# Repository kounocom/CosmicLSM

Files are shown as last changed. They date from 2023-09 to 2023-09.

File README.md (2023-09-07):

# CosmicLSM - An ESP32-C3 based custom SlimeVR PCB
Board Image
## Notes:

 - Currently untested!
 - Designed for handsoldering, BOM contains parts that are "extended" on JLC, or straight up not present
 - CPL file not tested at all
 - See "Outputs/" for production files
 - IMUs that are compatible :
 - - BMI160
 - - BMI270
 - - BMI323(?)
 - - LSM6DSV
 - - LSM6DSV16X
 - - ICM-40608
 - - Potentially more, but there will be no firmware support, even for some of the ones listed above
 - Special thanks to Gorbit99 and wigwagwent for their help with making this <3

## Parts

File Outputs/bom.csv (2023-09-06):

Designator | Footprint | Quantity | Value | LCSC Part #
C1, C2, C5 | 603 | 3 | 10u | C1691
C10, C8, C9 | 603 | 3 | 100n | C1591
C11, C12 | 603 | 2 | 1u | C1592
C3 | 603 | 1 | 4u7 | C1705
C4 | 603 | 1 | 22u | IGNORE
C6, C7 | 603 | 3 | 22u | C59461
D1 | 603 | 1 | WHITE | C84265
D2 | 603 | 1 | RED | C264473
D3 | 603 | 1 | GREEN | C965804
J1 | JST_PH_S2B-PH-SM4-TB_1x02-1MP_P2.00mm_Horizontal | 1 | BAT | C295747
J2 | JST_GH_SM05B-GHS-TB_1x05-1MP_P1.25mm_Horizontal | 1 | JST GH | C189896
J3 | USB_C_Receptacle_XKB_U262-16XN-4BVC11 | 1 | USB_C_Receptacle_USB2.0 | C2765186
L1 | 603 | 1 | 2u2 | C285966
L2 | 805 | 1 | 1uH | C433051
R1, R12, R2, R3 | 603 | 4 | 1k | C21190
R10, R11, R15, R7, R8 | 603 | 5 | 150k | C22807
R13 | 603 | 1 | 112.5k | C25808
R14 | 603 | 1 | 680k | C25822
R16 | 603 | 1 | 0r5 | C45312
R17, R18, R19, R20, R21, R4, R5 | 603 | 7 | 5k1 | C23186
R6 | 603 | 1 | 2r | C22977
R9 | 603 | 1 | 51k | C23196
SW1 | SW_SPDT_PCM12 | 1 | SW_SPDT | C109335
SW2 | SW_SPST_B3U-1000P | 1 | SW_SPST | C231329
U1, U2 | SOT-363_SC-70-6 | 2 | SMF05CT1G | C15879
U3 | SOT-23-5 | 1 | M3406 | C83224
U4 | HSOP-8-1EP_3.9x4.9mm_P1.27mm_EP2.41x3.1mm | 1 | IP2312 | C605433
U5 | Bosch_LGA-14_3x2.5mm_P0.5mm | 1 | LSM6DSV | IGNORE
U6 | MODULE_ESP32-C3-WROOM-02-H4 | 1 | ESP32-C3-WROOM-02-N4 | C2934560

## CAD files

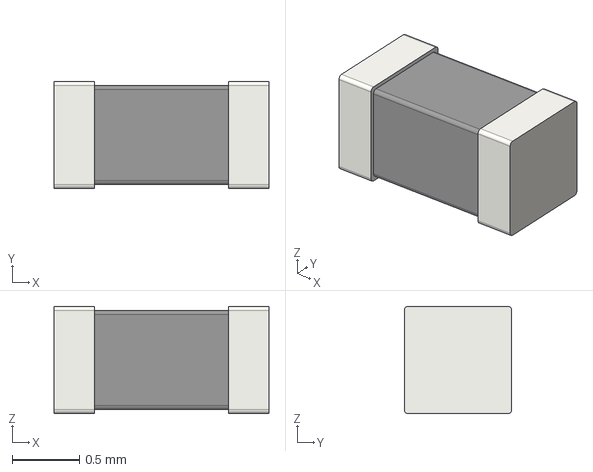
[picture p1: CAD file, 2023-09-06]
Data/CosmicLSM_3DModels/L_0603_1608Metric.step
1.60 x 0.8 x 0.8 mm

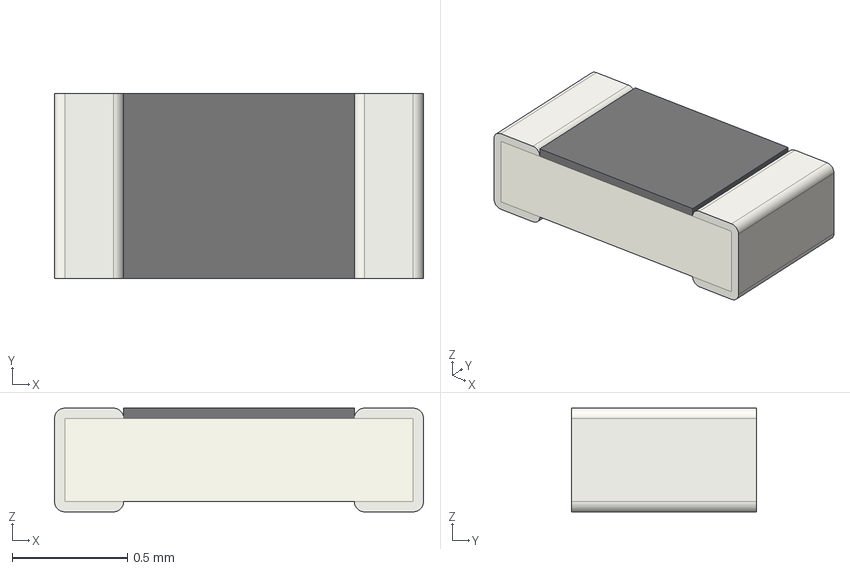
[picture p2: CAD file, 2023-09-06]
Data/CosmicLSM_3DModels/R_0603_1608Metric.step
1.60 x 0.8 x 0.45 mm

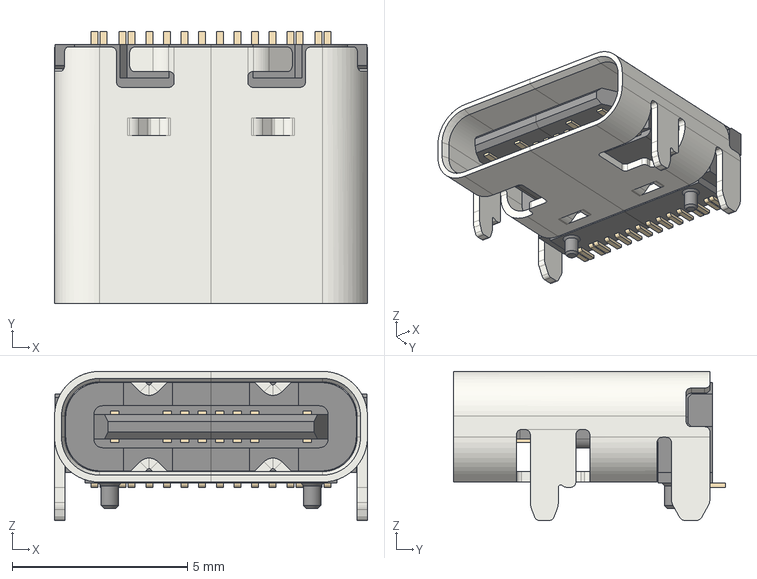
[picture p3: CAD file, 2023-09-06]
Data/CosmicLSM_3DModels/USB_C_Receptacle_GCT_USB4105-xx-A_16P_TopMnt_Horizontal.step
8.94 x 7.78 x 4.26 mm

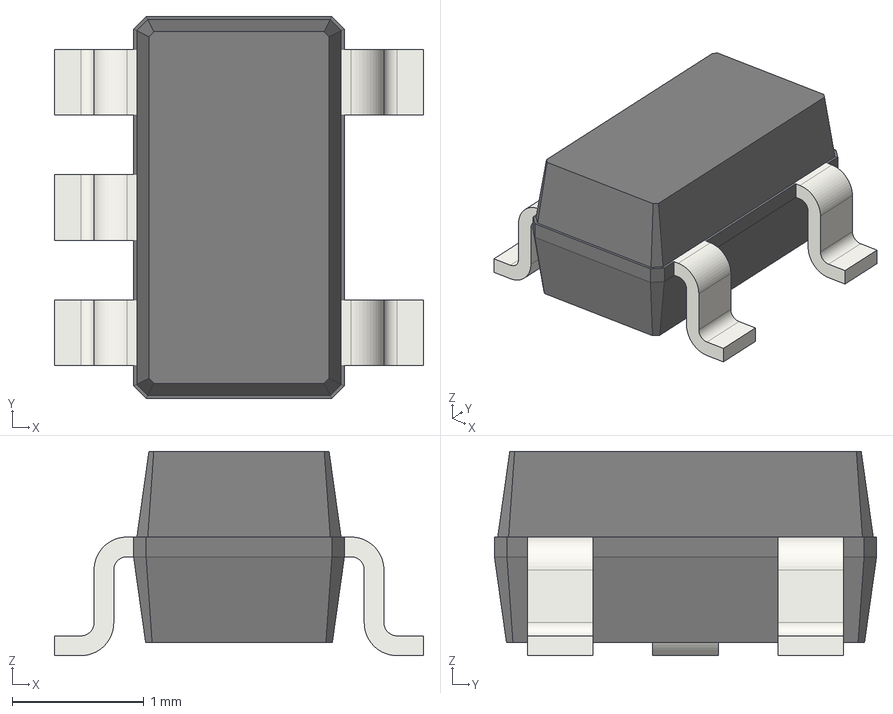
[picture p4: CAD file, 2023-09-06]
Data/CosmicLSM_3DModels/SOT-23-5.step
2.80 x 2.90 x 1.55 mm

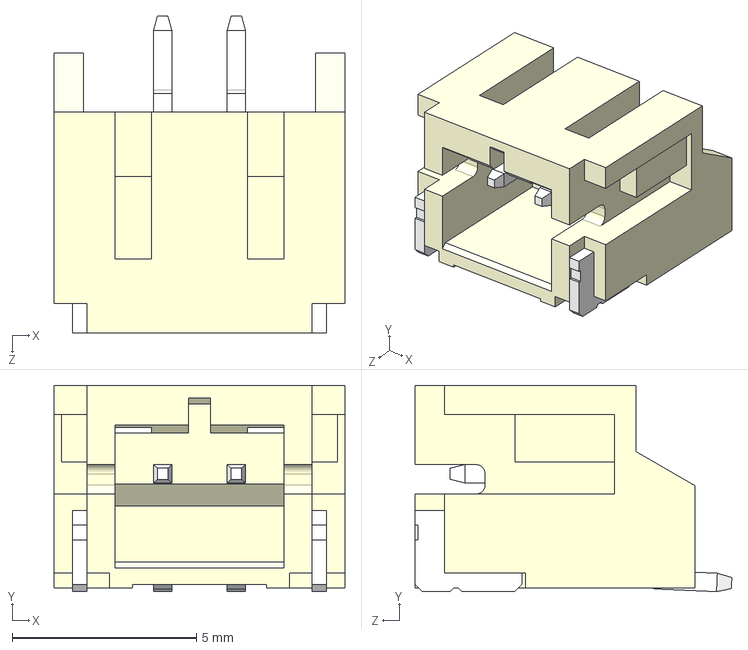
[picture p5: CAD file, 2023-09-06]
Data/CosmicLSM_3DModels/S2B-PH-SM4-TB(LF)(SN)--3DModel-STEP-56544.step
7.90 x 5.60 x 8.60 mm

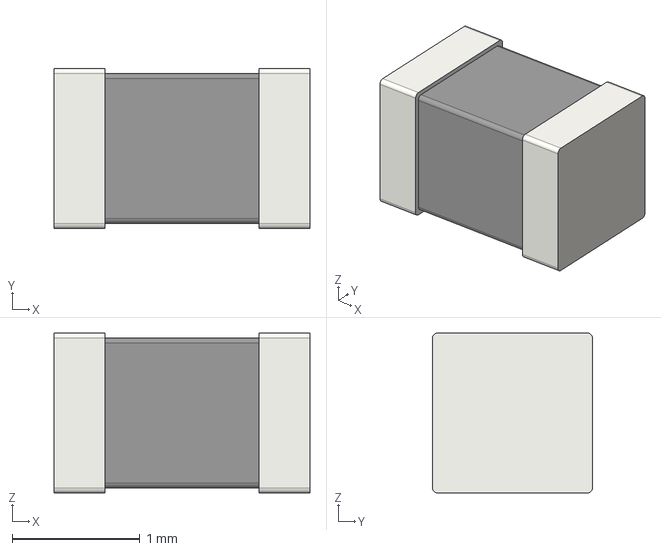
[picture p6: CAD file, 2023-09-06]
Data/CosmicLSM_3DModels/L_0805_2012Metric.step
2.00 x 1.25 x 1.25 mm

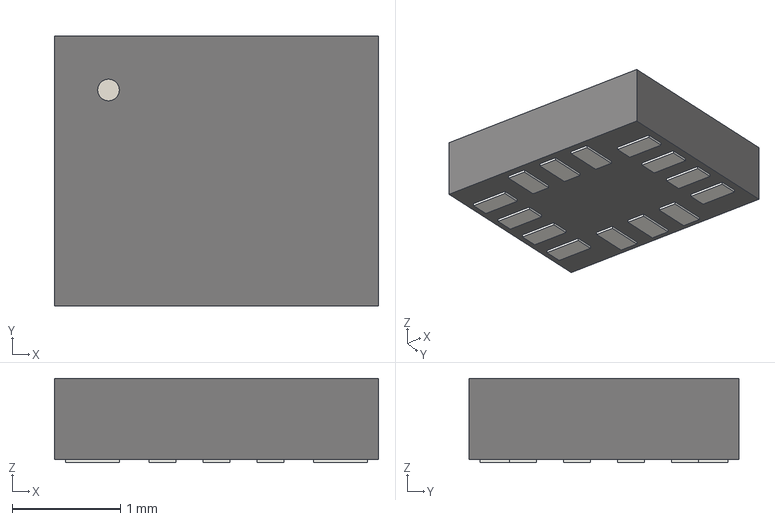
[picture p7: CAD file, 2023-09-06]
Data/CosmicLSM_3DModels/Bosch_LGA-14_3x2.5mm_P0.5mm.step
3.00 x 2.50 x 0.78 mm

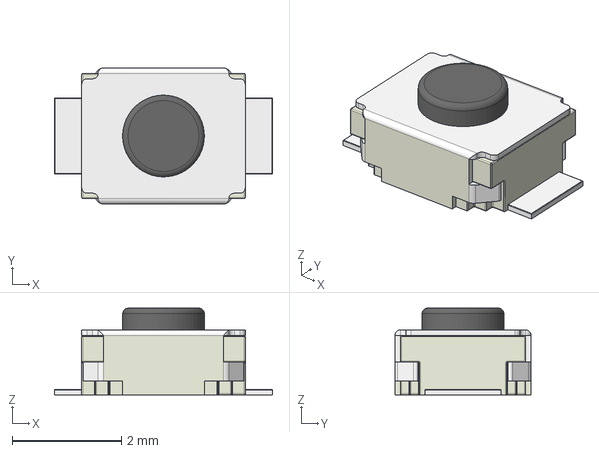
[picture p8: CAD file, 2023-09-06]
Data/CosmicLSM_3DModels/SW_SPST_B3U-1000P.step
4.00 x 2.50 x 1.59 mm

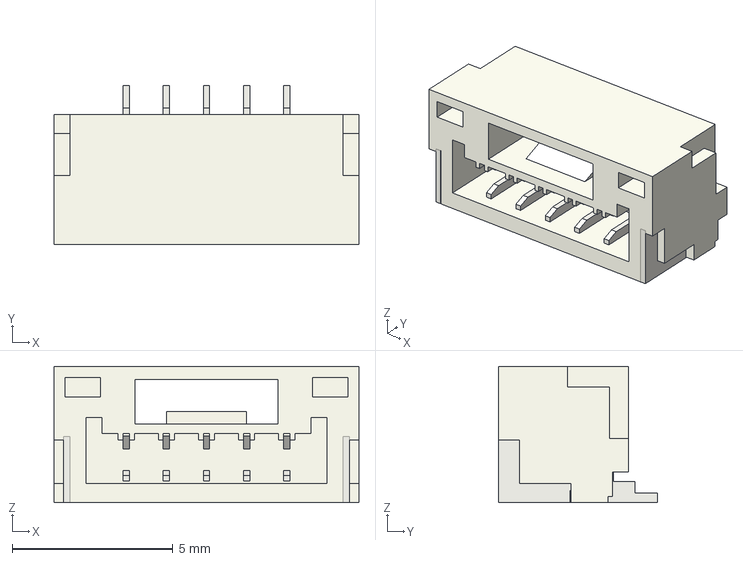
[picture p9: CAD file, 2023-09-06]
Data/CosmicLSM_3DModels/JST_GH_SM05B-GHS-TB_1x05-1MP_P1.25mm_Horizontal.step
9.50 x 4.95 x 4.25 mm

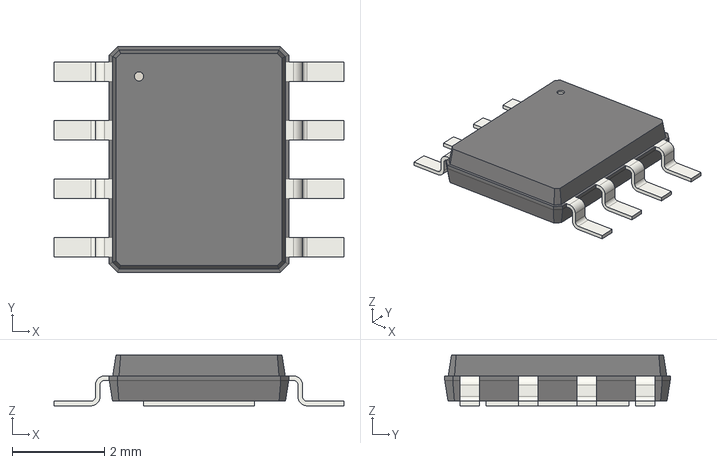
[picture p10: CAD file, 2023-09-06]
Data/CosmicLSM_3DModels/HSOP-8-1EP_3.9x4.9mm_P1.27mm_EP2.41x3.1mm.step
6.30 x 4.90 x 1.10 mm

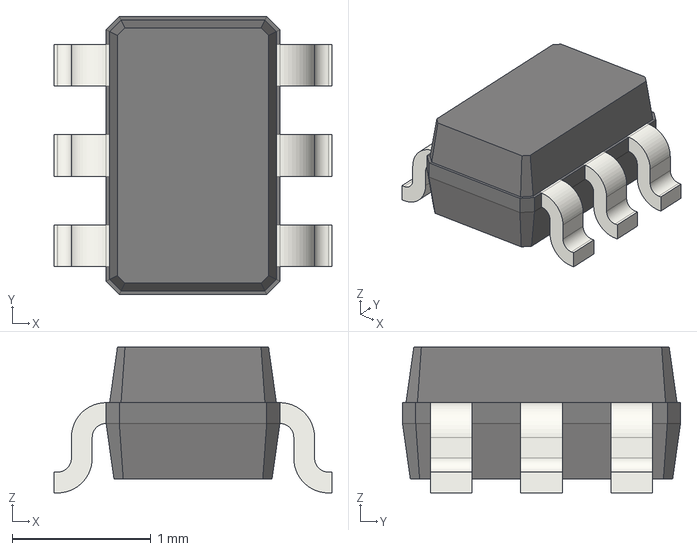
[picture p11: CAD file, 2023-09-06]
Data/CosmicLSM_3DModels/SOT-363_SC-70-6.step
2.00 x 2.00 x 1.05 mm

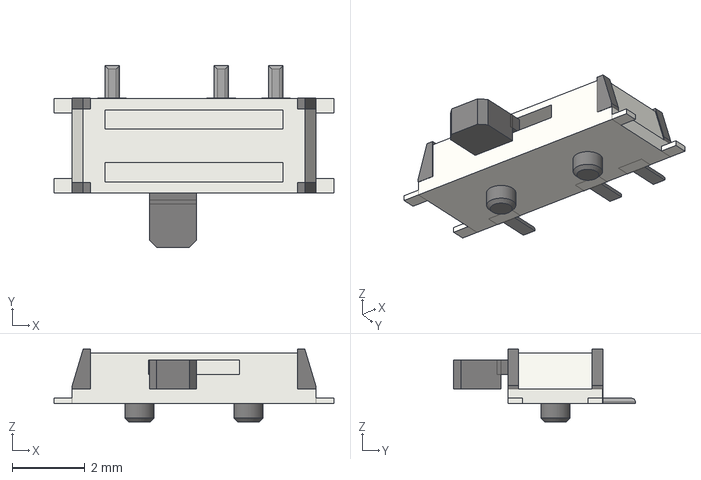
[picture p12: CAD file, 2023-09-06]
Data/CosmicLSM_3DModels/SW_SPDT_PCM12.step
7.70 x 5.00 x 2.00 mm

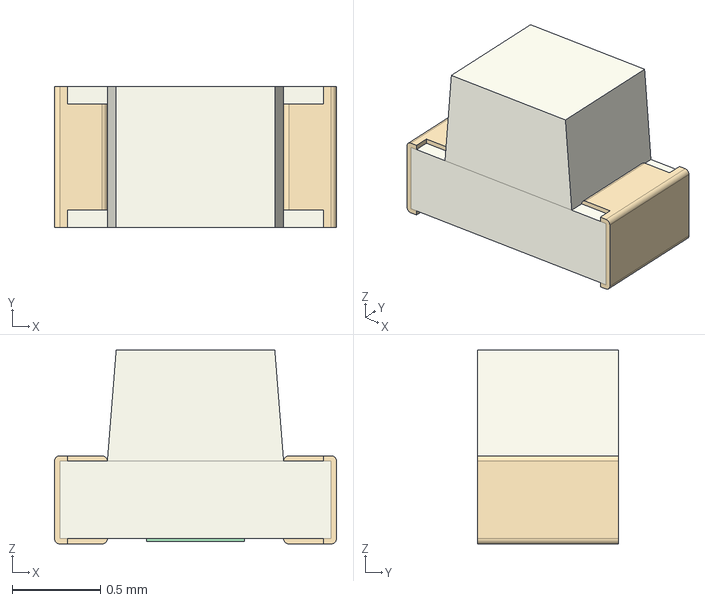
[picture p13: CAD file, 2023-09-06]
Data/CosmicLSM_3DModels/LED_0603_1608Metric.step
1.60 x 0.8 x 1.10 mm

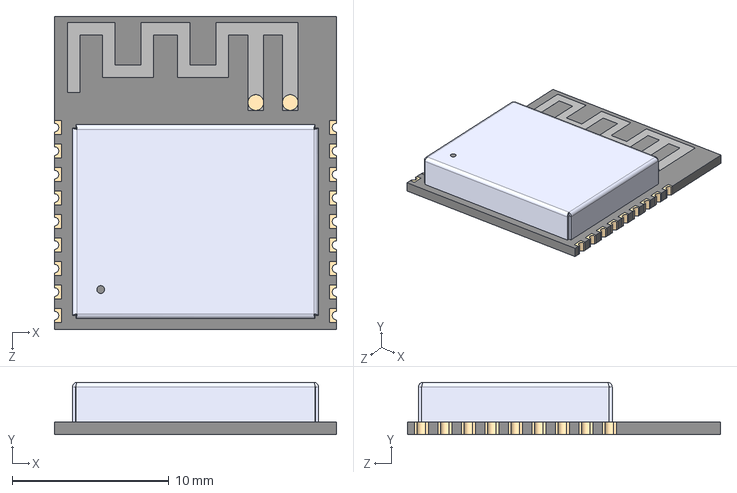
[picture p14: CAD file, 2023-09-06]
Data/CosmicLSM_3DModels/ESP32-C3-WROOM-02-N4.step
18.0 x 3.35 x 20.0 mm

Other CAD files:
Data/CosmicLSM_3DModels/C_0603_1608Metric.step

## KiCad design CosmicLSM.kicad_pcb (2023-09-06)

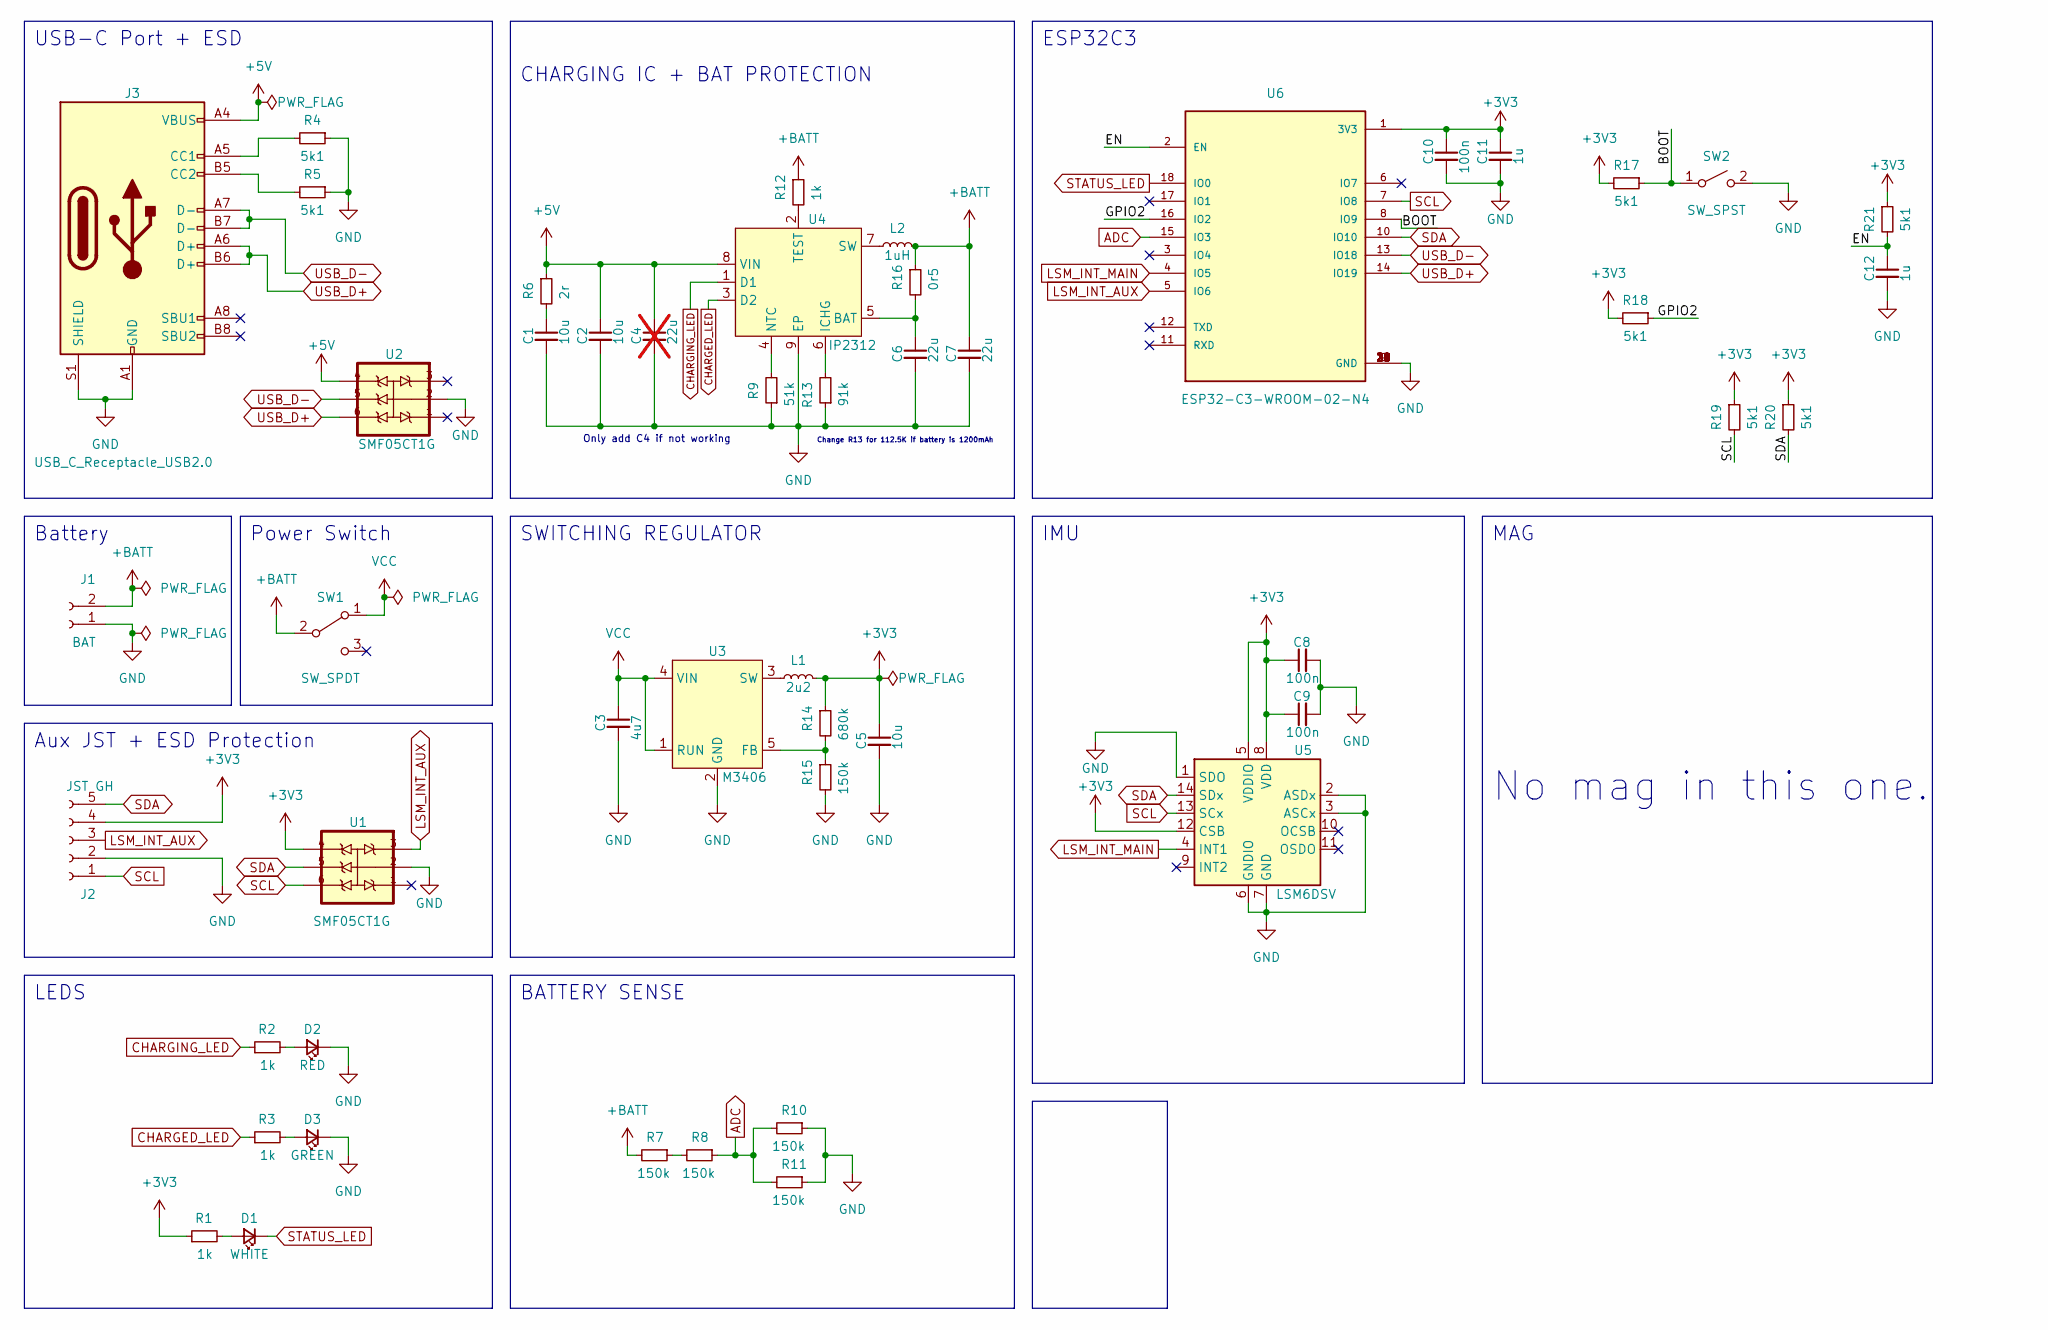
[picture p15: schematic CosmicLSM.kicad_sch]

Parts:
C1, C2, C5: 10u; C_0603_1608Metric_Pad1.08x0.95mm_HandSolder
C3: 4u7; C_0603_1608Metric_Pad1.08x0.95mm_HandSolder
C4: 22u; C_0603_1608Metric_Pad1.08x0.95mm_HandSolder; not fitted
C6, C7: 22u; C_0603_1608Metric_Pad1.08x0.95mm_HandSolder
C8, C9, C10: 100n; C_0603_1608Metric_Pad1.08x0.95mm_HandSolder
C11, C12: 1u; C_0603_1608Metric_Pad1.08x0.95mm_HandSolder
D1: WHITE; LED_0603_1608Metric_Pad1.05x0.95mm_HandSolder
D2: RED; LED_0603_1608Metric_Pad1.05x0.95mm_HandSolder
D3: GREEN; LED_0603_1608Metric_Pad1.05x0.95mm_HandSolder
J1: BAT; JST_PH_S2B-PH-SM4-TB_1x02-1MP_P2.00mm_Horizontal
J2: JST GH; JST_GH_SM05B-GHS-TB_1x05-1MP_P1.25mm_Horizontal
J3: USB_C_Receptacle_USB2.0; USB_C_Receptacle_XKB_U262-16XN-4BVC11
L1: 2u2; L_0603_1608Metric_Pad1.05x0.95mm_HandSolder
L2: 1uH; L_0805_2012Metric_Pad1.15x1.40mm_HandSolder
R1, R2, R3, R12: 1k; R_0603_1608Metric_Pad0.98x0.95mm_HandSolder
R4, R5, R17, R18, R19, R20, R21: 5k1; R_0603_1608Metric_Pad0.98x0.95mm_HandSolder
R6: 2r; R_0603_1608Metric_Pad0.98x0.95mm_HandSolder
R7, R8, R10, R11, R15: 150k; R_0603_1608Metric_Pad0.98x0.95mm_HandSolder
R9: 51k; R_0603_1608Metric_Pad0.98x0.95mm_HandSolder
R13: 91k; R_0603_1608Metric_Pad0.98x0.95mm_HandSolder
R14: 680k; R_0603_1608Metric_Pad0.98x0.95mm_HandSolder
R16: 0r5; R_0603_1608Metric_Pad0.98x0.95mm_HandSolder
SW1: SW_SPDT; SW_SPDT_PCM12
SW2: SW_SPST; SW_SPST_B3U-1000P
U1, U2: SMF05CT1G; SOT-363_SC-70-6
U3: M3406; SOT-23-5; LCSC C83224
U4: IP2312; HSOP-8-1EP_3.9x4.9mm_P1.27mm_EP2.41x3.1mm
U5: LSM6DSV; Bosch_LGA-14_3x2.5mm_P0.5mm
U6: ESP32-C3-WROOM-02-N4; MODULE_ESP32-C3-WROOM-02-H4

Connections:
+3V3: C5.1, C8.1, C9.1, C10.1, C11.1, J2.4, L1.2, R1.1, R14.1, R17.2, R18.2, R19.1, R20.1, R21.1, U1.4, U5.5 (VDDIO), U5.8 (VDD), U5.12 (CSB), U6.1 (3V3)
+5V: C2.1, C4.1, J3.A4 (VBUS), J3.A9 (VBUS), J3.B4 (VBUS), J3.B9 (VBUS), R6.1, U2.4, U4.8 (VIN)
+BATT: C7.1, J1.2 (Pin_1), L2.2, R7.2, R12.1, R16.1, SW1.2 (B)
/BOOT: R17.1, SW2.1 (A), U6.8 (IO9)
/EN: C12.1, R21.2, U6.2 (EN)
/GPIO2: R18.1, U6.16 (IO2)
ADC: R8.1, R10.2, R11.2, U6.15 (IO3)
CHARGED_LED: R3.1, U4.3 (D2)
CHARGING_LED: R2.1, U4.1 (D1)
GND: C1.2, C2.2, C3.2, C4.2, C5.2, C6.2, C7.2, C8.2, C9.2, C10.2, C11.2, C12.2, D2.1 (K), D3.1 (K), J1.1 (Pin_2), J2.2, J3.A1 (GND), J3.A12 (GND), J3.B1 (GND), J3.B12 (GND), J3.S1 (SHIELD), R4.1, R5.1, R9.1, R10.1, R11.1, R13.1, R15.2, SW2.2 (B), U1.2, U2.2, U3.2 (GND), U4.9 (EP), U5.1 (SDO), U5.2 (ASDx), U5.3 (ASCx), U5.6 (GNDIO), U5.7 (GND), U6.9 (GND), U6.19 (GND), U6.20 (GND), U6.21 (GND), U6.22 (GND), U6.23 (GND), U6.24 (GND), U6.25 (GND), U6.26 (GND), U6.27 (GND), U6.28 (GND), U6.29 (GND), U6.30 (GND), U6.31 (GND), U6.32 (GND), U6.33 (GND), U6.34 (GND), U6.35 (GND), U6.36 (GND), U6.37 (GND), U6.38 (GND), U6.39 (GND)
LSM_INT_AUX: J2.3, U1.3, U6.5 (IO6)
LSM_INT_MAIN: U5.4 (INT1), U6.4 (IO5)
unnamed: C1.1, R6.2
unnamed: D1.2 (A), R1.2
unnamed: D2.2 (A), R2.2
unnamed: D3.2 (A), R3.2
unnamed: J3.A5 (CC1), R4.2
unnamed: J3.B5 (CC2), R5.2
unnamed: R7.1, R8.2
unnamed: R14.2, R15.1, U3.5 (FB)
unnamed: L1.1, U3.3 (SW)
unnamed: C6.1, R16.2, U4.5 (BAT)
unnamed: R13.2, U4.6 (ICHG)
unnamed: R9.2, U4.4 (NTC)
unnamed: L2.1, U4.7 (SW)
unnamed: R12.2, U4.2 (TEST)
SCL: J2.1, R19.2, U1.6, U5.13 (SCx), U6.7 (IO8)
SDA: J2.5, R20.2, U1.5, U5.14 (SDx), U6.10 (IO10)
STATUS_LED: D1.1 (K), U6.18 (IO0)
USB_D+: J3.A6 (D+), J3.B6 (D+), U2.6, U6.14 (IO19)
USB_D-: J3.A7 (D-), J3.B7 (D-), U2.5, U6.13 (IO18)
VCC: C3.1, SW1.1 (A), U3.1 (RUN), U3.4 (VIN)

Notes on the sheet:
Battery
Only add C4 if not working
SWITCHING REGULATOR
No mag in this one.
ESP32C3
MAG
USB-C Port + ESD
IMU
Aux JST + ESD Protection
BATTERY SENSE
Change R13 for 112.5K if battery is 1200mAh
Power Switch
CHARGING IC + BAT PROTECTION
LEDS

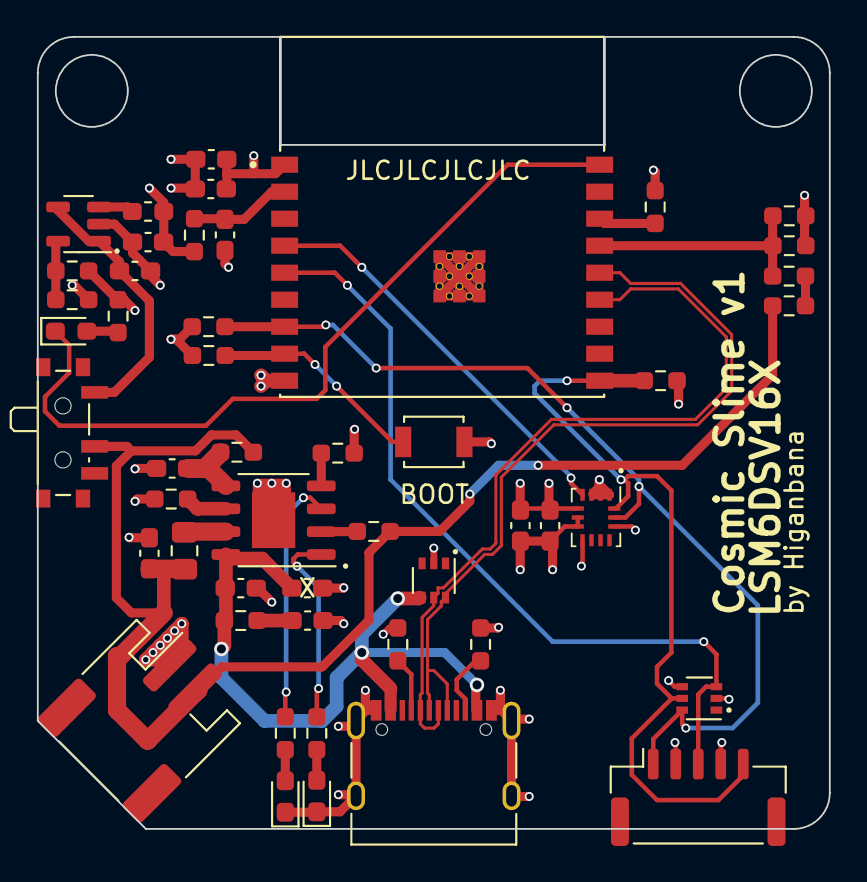
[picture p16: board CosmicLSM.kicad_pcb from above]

Board: 4 copper layers, 44.0 x 44.0 mm, 49 parts (0 on the bottom side), 32 nets.

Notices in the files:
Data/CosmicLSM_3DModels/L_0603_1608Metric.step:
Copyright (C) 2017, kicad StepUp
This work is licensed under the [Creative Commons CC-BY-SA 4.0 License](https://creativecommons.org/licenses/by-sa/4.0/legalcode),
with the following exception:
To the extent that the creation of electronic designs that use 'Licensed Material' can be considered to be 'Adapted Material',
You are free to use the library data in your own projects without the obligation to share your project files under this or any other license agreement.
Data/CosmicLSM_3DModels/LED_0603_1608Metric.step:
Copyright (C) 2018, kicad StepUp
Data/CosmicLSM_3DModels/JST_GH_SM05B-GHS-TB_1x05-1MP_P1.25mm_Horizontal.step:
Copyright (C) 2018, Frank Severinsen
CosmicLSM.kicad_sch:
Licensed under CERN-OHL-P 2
